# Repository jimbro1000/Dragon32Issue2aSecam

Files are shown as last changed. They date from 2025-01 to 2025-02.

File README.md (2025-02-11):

# Dragon 32 Issue 2a (SECAM) Reproduction

This repository contains the KiCad project files
to reproduce the SECAM variation of the Dragon 32
Issue 2a main board.

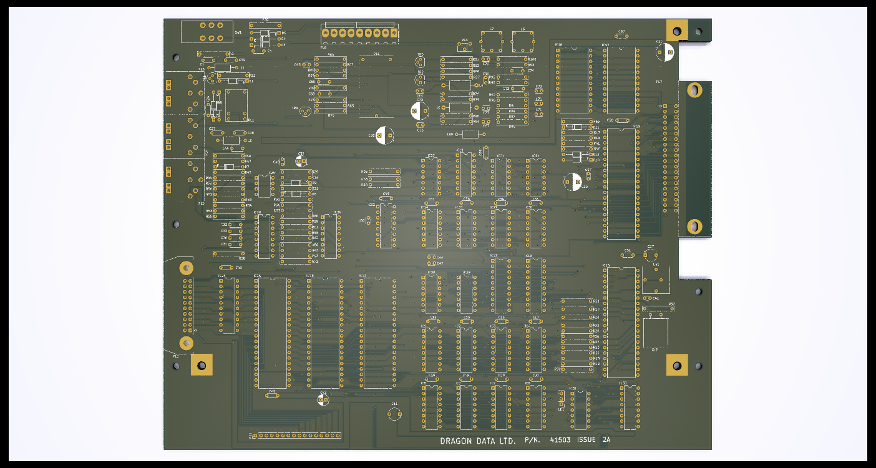
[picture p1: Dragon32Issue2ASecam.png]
Render of PCB top


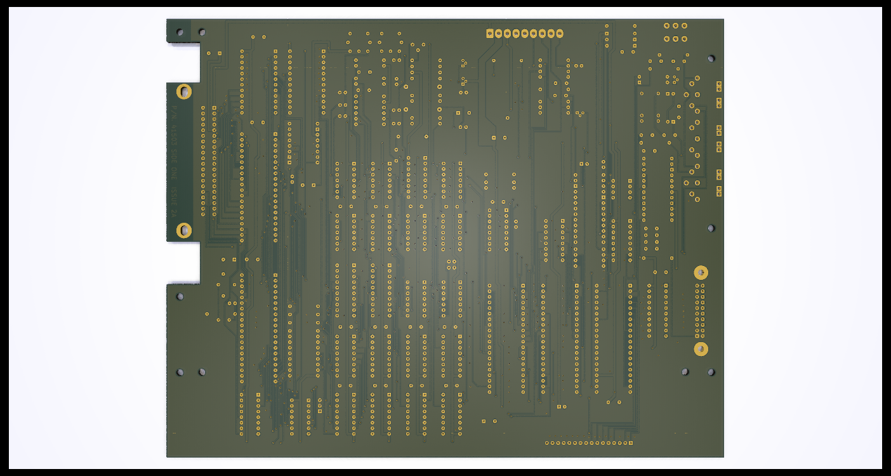
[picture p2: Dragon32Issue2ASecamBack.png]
Render of PCB back


This design requires the SECAM power board to operate
correctly and will not work with the standard board.
See https://github.com/jimbro1000/Dragon32PowerSecam

## Notes

The board incorporates some factory bodges to simplify
assembly efforts.

A front and back ground plane fill has also been added
along with effort to make sure that a ground plane is 
present across most of the board.

## Video Circuit Changes

Compared to the original Dragon 32 (in PAL or NTSC form)
the SECAM version of the design requires a significant 
level of additional work to generate a viable composite
signal.

The most significant change is that the board does not 
make use of a modulator chip (the LM1889N is used on
the PAL version). Instead the generation of the FM based
composite signal is generated through discrete components.

The board is effectively split into two areas. The regular
PAL design (with a few small tweaks) and the SECAM composite
generation - located in the north section of the PCB.

## Power Board Changes

While the same 9 wire interconnect is present on both
designs, the SECAM version repurposes the 5 non-voltage
connections making the power board incompatible with the
PAL/NTSC main board and the SECAM main board incompatible
with the PAL/NTSC power board.

The original pin out provided ground, composite, audio, 5v
and a bias voltage.

The SECAM board uses the same pins as audio, composite,
luma, phiA and phiB (the last 3 forming a YPrPb signal). 
By passing the raw output of the VDG to the power board
there is space to perform additional transformation into
a genuine RGB output that is sorely missing from the original.

### RGB Calculation

The transformation is performed in two stages - first to
homogenise the signal levels of the VDG output (while it 
broadly follows the YPrPb format it doesn't meet the requried
signal voltages). The second stage performs some analogue
computation to create R-Y, G-Y and B-Y components. These
then can be added to the homogenised Y signal to create
the three R, G and B signals.

An exta calculation is needed to isolate the sync signal
that appears on the G channel.

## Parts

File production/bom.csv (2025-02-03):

Designator | Footprint | Quantity | Value | LCSC Part #
C1, C38, C39, C43, C45 | C_Disc_D4.3mm_W1.9mm_P5.00mm | 5 | 0.01uF
C11, C37 | CP_Radial_Tantal_D5.5mm_P5.00mm | 2 | 4.7uF
C14, C15, C16, C17, C18, C19, C20, C21, C27, C4, C50, C51, C52 | C_Disc_D4.3mm_W1.9mm_P5.00mm | 13 | 0.1uF
C22, C23, C36 | CP_Radial_D8.0mm_P5.00mm | 3 | 100uF
C26 | C_Disc_D4.3mm_W1.9mm_P5.00mm | 1 | 2.2nF
C30, C31, C32, C33, C44 | C_Disc_D5.0mm_W2.5mm_P5.00mm | 5 | 22nF
C35, C42 | CP_Radial_D5.0mm_P2.50mm | 2 | 10uF
C40 | C_Radial_Special | 1 | 22pF
C41 | C_Disc_D3.0mm_W1.6mm_P2.50mm | 1 | 33pF
C46, C60 | C_Disc_D3.0mm_W2.0mm_P2.50mm | 2 | 180pF
C47, C61, C65, C67, C70, C71, C72, C75, C76, C77 | C_Disc_D3.0mm_W2.0mm_P2.50mm | 10 | 100pF
C48 | C_Disc_D3.0mm_W2.0mm_P2.50mm | 1 | 22pF
C49, C53, C54, C55, C56 | C_Disc_D4.3mm_W1.9mm_P5.00mm | 5 | 100nF
C68, C69, C73, C74 | C_Disc_D4.7mm_W2.5mm_P5.00mm | 4 | 100nF
C78 | CP_Radial_D8.0mm_P5.00mm | 1 | 10uF
C97, C98 | C_Disc_D3.0mm_W2.0mm_P2.50mm | 2 | 33nF
C99 | C_Disc_D4.7mm_W2.5mm_P5.00mm | 1 | 180pF
D1, D10, D11, D12, D2, D3, D4, D5, D6, D7, D8, D9 | D_DO-35_SOD27_P12.70mm_Horizontal | 12 | 1N914
DL1 | Delay_Line-V9663 | 1 | 390ns 1K1
IC1, IC2, IC3, IC4, IC5, IC6, IC7, IC8 | DIP-16_W7.62mm | 8 | M3732H-20RS
IC11 | DIP-16_W7.62mm | 1 | MC14053
IC12 | DIP-40_W15.24mm | 1 | MC6847
IC13 | DIP-20_W7.62mm | 1 | 74LS273N
IC14 | DIP-14_W7.62mm | 1 | 74LS86AN
IC15 | DIP-40_W15.24mm | 1 | MC6883
IC16, IC24 | DIP-20_W7.62mm | 2 | 74LS244N
IC17, IC18 | DIP-24_W15.24mm | 2 | 68A364
IC19 | DIP-40_W15.24mm | 1 | MC6809E
IC20 | DIP-16_W7.62mm | 1 | MC14529B
IC21 | DIP-14_W7.62mm | 1 | 74LS74
IC22 | DIP-14_W7.62mm | 1 | 74LS00N
IC23 | DIP-14_W7.62mm | 1 | 74ALS74N
IC25 | DIP-8_W7.62mm | 1 | LM393P
IC26, IC35 | DIP-40_W15.24mm | 2 | MC6821
IC27 | DIP-14_W7.62mm | 1 | 74LS20N
IC28, IC29 | DIP-14_W7.62mm | 2 | 74LS393N
IC30 | DIP-14_W7.62mm | 1 | 74LS32N
IC31 | DIP-14_W7.62mm | 1 | 74LS02N
IC32 | DIP-16_W7.62mm | 1 | 74LS390
IC33 | DIP-16_W7.62mm | 1 | 74LS138N
IC34 | DIP-16_W7.62mm | 1 | MC14050BCP
IC44 | DIP-14_W7.62mm | 1 | MC3346
L1, L2, L99 | L_Axial_L7.0mm_D3.3mm_P12.70mm_Horizontal_Fastron_MICC | 3 | 3.3uH
L4 | L_Axial_L9.5mm_D4.0mm_P15.24mm_Horizontal_Fastron_SMCC | 1 | 22uH
L5 | L_Axial_L9.5mm_D4.0mm_P15.24mm_Horizontal_Fastron_SMCC | 1 | 3.3uH
L6, L7 | TOKO_RCL_10K | 2 | 10.7MHz
LK2 | PinHeader_1x03_P2.54mm_Vertical | 1 | LK2
PL1 | PinHeader_1x16_P2.54mm_Vertical | 1 | Dragon Keyboard
PL2 | IDC-Header_2x10-1MP_P2.54mm_Latch_Horizontal | 1 | Printer
PL3 | DIN-6_DELTRON_671-0601_Horizontal | 1 | DIN-6 J/S R
PL4 | DIN-5_DELTRON_671-0501_45deg_Horizontal | 1 | DIN-5 (180) Cassette
PL5 | DIN-6_DELTRON_671-0601_Horizontal | 1 | DIN-6 J/S L
PL6 | Molex_KK-396_A-41791-0009_1x09_P3.96mm_Vertical | 1 | Power Board Interconnect
PL7 | Edge_2x20_P2.54mm_OvalMP | 1 | EDAC 392-040-558-201
R1 | R_Axial_DIN0309_L9.0mm_D2.5mm_P12.70mm_Horizontal | 1 | 100R
R100, R91, R92, R93 | R_Axial_DIN0309_L9.0mm_D2.5mm_P12.70mm_Horizontal | 4 | 6K5
R12, R19, R20, R21, R22, R23, R24, R25, R26, R27, R28 | R_Axial_DIN0309_L9.0mm_D2.5mm_P12.70mm_Horizontal | 11 | 22R
R13, R14, R30, R31, R32, R38, R39, R40, R41, R63, R72 | R_Axial_DIN0309_L9.0mm_D2.5mm_P12.70mm_Horizontal | 11 | 4K7
R16 | R_Axial_DIN0309_L9.0mm_D2.5mm_P12.70mm_Horizontal | 1 | 33K
R29 | R_Axial_DIN0309_L9.0mm_D2.5mm_P12.70mm_Horizontal | 1 | 68K
R33 | R_Axial_DIN0309_L9.0mm_D2.5mm_P12.70mm_Horizontal | 1 | 1K8
R34, R47 | R_Axial_DIN0309_L9.0mm_D2.5mm_P12.70mm_Horizontal | 2 | 8K2
R35 | R_Axial_DIN0309_L9.0mm_D2.5mm_P12.70mm_Horizontal | 1 | 12K
R36, R64 | R_Axial_DIN0309_L9.0mm_D2.5mm_P12.70mm_Horizontal | 2 | 100K
R37 | R_Axial_DIN0309_L9.0mm_D2.5mm_P12.70mm_Horizontal | 1 | 1K5
R42, R43, R55, R56 | R_Axial_DIN0309_L9.0mm_D2.5mm_P12.70mm_Horizontal | 4 | 10K
R45 | R_Axial_DIN0309_L9.0mm_D2.5mm_P12.70mm_Horizontal | 1 | 6K8
R46 | R_Axial_DIN0309_L9.0mm_D2.5mm_P12.70mm_Horizontal | 1 | 220R
R48 | R_Axial_DIN0309_L9.0mm_D2.5mm_P12.70mm_Horizontal | 1 | 15K
R49, R54 | R_Axial_DIN0309_L9.0mm_D2.5mm_P12.70mm_Horizontal | 2 | 1K
R50, R52 | R_Axial_DIN0309_L9.0mm_D2.5mm_P12.70mm_Horizontal | 2 | 56K
R51 | R_Axial_DIN0309_L9.0mm_D2.5mm_P12.70mm_Horizontal | 1 | 1M5
R53 | R_Axial_DIN0309_L9.0mm_D2.5mm_P12.70mm_Horizontal | 1 | 10M
R57 | R_Axial_DIN0309_L9.0mm_D2.5mm_P12.70mm_Horizontal | 1 | 20K 1%
R58 | R_Axial_DIN0309_L9.0mm_D2.5mm_P12.70mm_Horizontal | 1 | 80K6 1%
R59 | R_Axial_DIN0309_L9.0mm_D2.5mm_P12.70mm_Horizontal | 1 | 160K 1%
R60 | R_Axial_DIN0309_L9.0mm_D2.5mm_P12.70mm_Horizontal | 1 | 330K 1%
R61 | R_Axial_DIN0309_L9.0mm_D2.5mm_P12.70mm_Horizontal | 1 | 40K2 1%
R62 | R_Axial_DIN0309_L9.0mm_D2.5mm_P12.70mm_Horizontal | 1 | 10K 1%
R75, R78, R79, R80, R81, R82, R83, R84, R85, R86, R87, R88, R90, R96 | R_Axial_DIN0309_L9.0mm_D2.5mm_P12.70mm_Horizontal | 14 | 47K
R76, R77, R89 | R_Axial_DIN0309_L9.0mm_D2.5mm_P12.70mm_Horizontal | 3 | 1200uH
R94, R99 | R_Axial_DIN0309_L9.0mm_D2.5mm_P12.70mm_Horizontal | 2 | 1K6
R95, R98 | R_Axial_DIN0309_L9.0mm_D2.5mm_P12.70mm_Horizontal | 2 | 470uH
R97 | R_Axial_DIN0309_L9.0mm_D2.5mm_P12.70mm_Horizontal | 1 | 270R
RL1 | OMRON_G2E | 1 | OMRON G2E
SW1 | Button_AlpsAlpine_SPUN190900 | 1 | RESET
TR1 | TO-92 | 1 | BC141
TR2, TR3, TR4 | TO-92 | 3 | BC238B
VR1 | Potentiometer_ACP_CA6-H2,5_Horizontal | 1 | 10K
XL2 | Crystal_HC49-U_Horizontal | 1 | 14.31818MHz

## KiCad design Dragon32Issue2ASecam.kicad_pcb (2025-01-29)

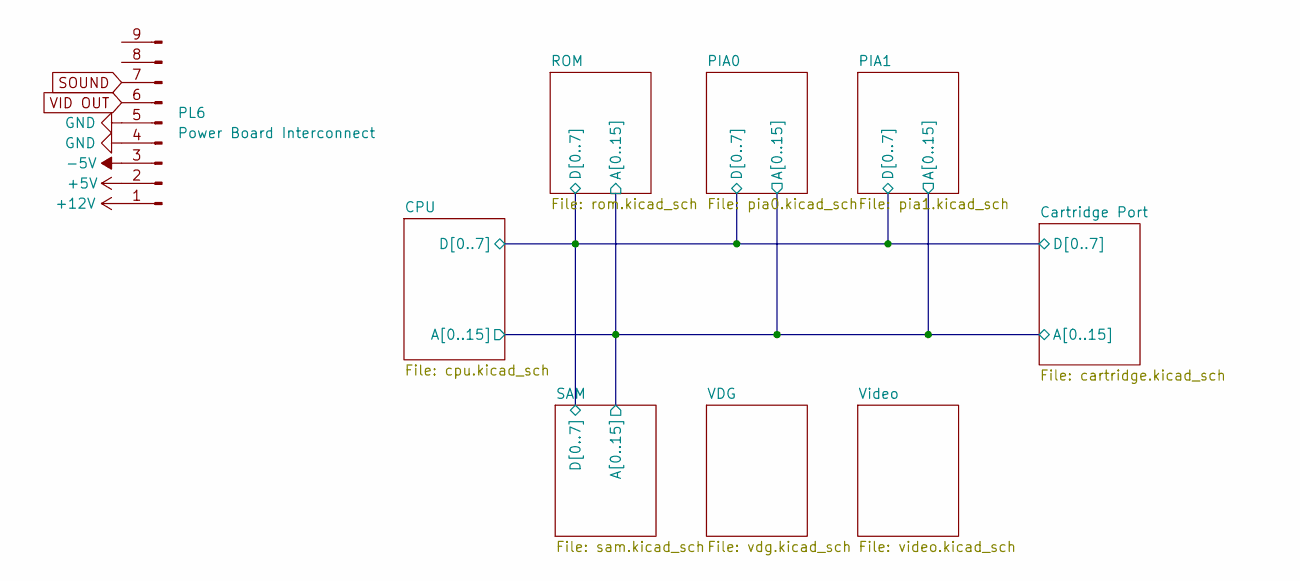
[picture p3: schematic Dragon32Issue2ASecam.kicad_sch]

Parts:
PL6: Power Board Interconnect; Molex_KK-396_A-41791-0009_1x09_P3.96mm_Vertical; DigiKey 2057-LHD-09-TS-ND

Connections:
+5V: PL6.2; also elsewhere on the board
+12V: PL6.1; also elsewhere on the board
-5V: PL6.3
GND: PL6.4, PL6.5; also elsewhere on the board
SOUND: PL6.7; also elsewhere on the board
VID OUT: PL6.6

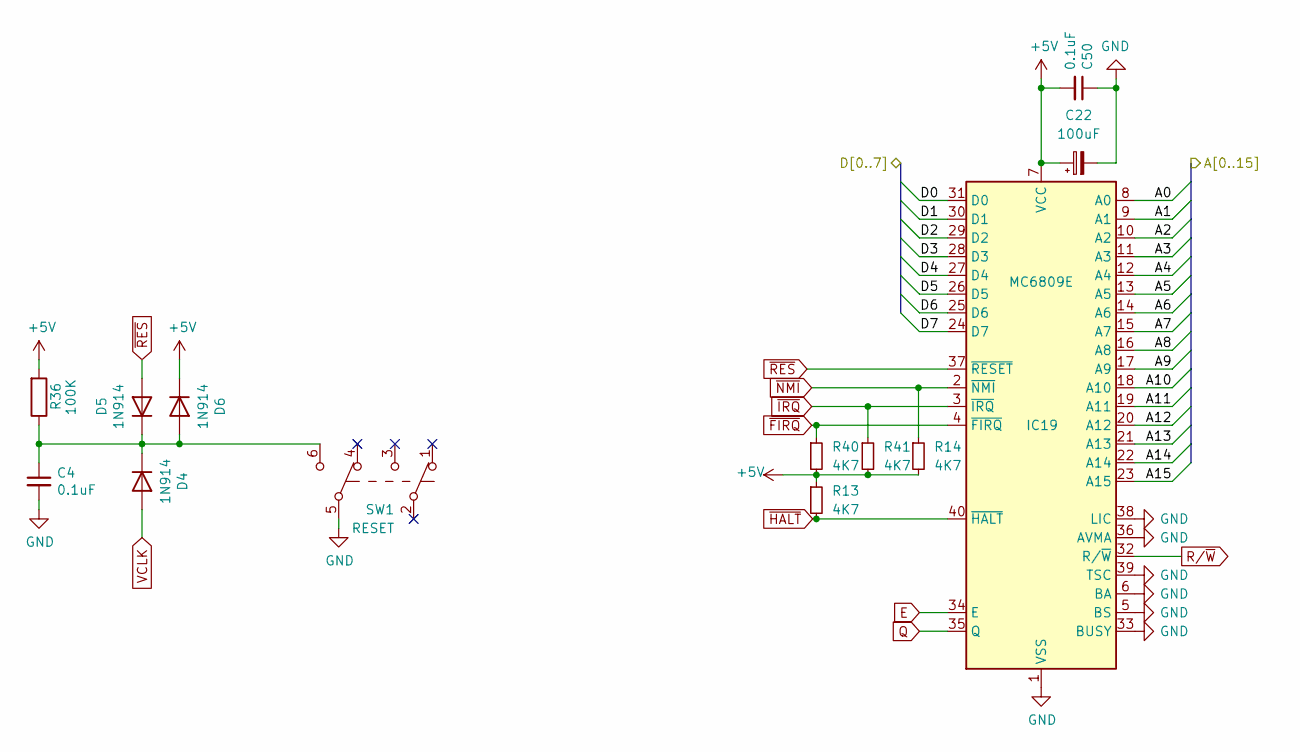
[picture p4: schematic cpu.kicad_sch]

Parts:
C4, C50: 0.1uF; C_Disc_D4.3mm_W1.9mm_P5.00mm; DigiKey BC1101CT-ND
C22: 100uF; CP_Radial_D8.0mm_P5.00mm; DigiKey 732-8598-1-ND
D4, D5, D6: 1N914; D_DO-35_SOD27_P12.70mm_Horizontal; DigiKey 1N914FS-ND
IC19: MC6809E; DIP-40_W15.24mm
R13, R14, R40, R41: 4K7; R_Axial_DIN0309_L9.0mm_D2.5mm_P12.70mm_Horizontal; DigiKey CF14JT4K70CT-ND
R36: 100K; R_Axial_DIN0309_L9.0mm_D2.5mm_P12.70mm_Horizontal; DigiKey CF14JT100KCT-ND
SW1: RESET; Button_AlpsAlpine_SPUN190900; DigiKey 401-1225-ND

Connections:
+5V: C22.1, C50.2, D6.1 (K), IC19.7 (VCC), R13.1, R14.2, R36.2, R40.2, R41.2; also elsewhere on the board
/CPU/A0: IC19.8 (A0); also elsewhere on the board
/CPU/A1: IC19.9 (A1); also elsewhere on the board
/CPU/A2: IC19.10 (A2); also elsewhere on the board
/CPU/A3: IC19.11 (A3); also elsewhere on the board
/CPU/A4: IC19.12 (A4); also elsewhere on the board
/CPU/A5: IC19.13 (A5); also elsewhere on the board
/CPU/A6: IC19.14 (A6); also elsewhere on the board
/CPU/A7: IC19.15 (A7); also elsewhere on the board
/CPU/A8: IC19.16 (A8); also elsewhere on the board
/CPU/A9: IC19.17 (A9); also elsewhere on the board
/CPU/A10: IC19.18 (A10); also elsewhere on the board
/CPU/A11: IC19.19 (A11); also elsewhere on the board
/CPU/A12: IC19.20 (A12); also elsewhere on the board
/CPU/A13: IC19.21 (A13); also elsewhere on the board
/CPU/A14: IC19.22 (A14); also elsewhere on the board
/CPU/A15: IC19.23 (A15); also elsewhere on the board
/CPU/D0: IC19.31 (D0); also elsewhere on the board
/CPU/D1: IC19.30 (D1); also elsewhere on the board
/CPU/D2: IC19.29 (D2); also elsewhere on the board
/CPU/D3: IC19.28 (D3); also elsewhere on the board
/CPU/D4: IC19.27 (D4); also elsewhere on the board
/CPU/D5: IC19.26 (D5); also elsewhere on the board
/CPU/D6: IC19.25 (D6); also elsewhere on the board
/CPU/D7: IC19.24 (D7); also elsewhere on the board
E: IC19.34 (E); also elsewhere on the board
GND: C4.2, C22.2, C50.1, IC19.1 (VSS), IC19.5 (BS), IC19.6 (BA), IC19.33 (BUSY), IC19.36 (AVMA), IC19.38 (LIC), IC19.39 (TSC), SW1.5 (B); also elsewhere on the board
unnamed: C4.1, D4.1 (K), D5.1 (K), D6.2 (A), R36.1, SW1.6 (C)
Q: IC19.35 (Q); also elsewhere on the board
R/~W: IC19.32 (R/~W); also elsewhere on the board
VCLK: D4.2 (A); also elsewhere on the board
~FIRQ: IC19.4 (~FIRQ), R40.1; also elsewhere on the board
~HALT: IC19.40 (~HALT), R13.2; also elsewhere on the board
~IRQ: IC19.3 (~IRQ), R41.1; also elsewhere on the board
~NMI: IC19.2 (~NMI), R14.1; also elsewhere on the board
~RES: D5.2 (A), IC19.37 (~RESET); also elsewhere on the board

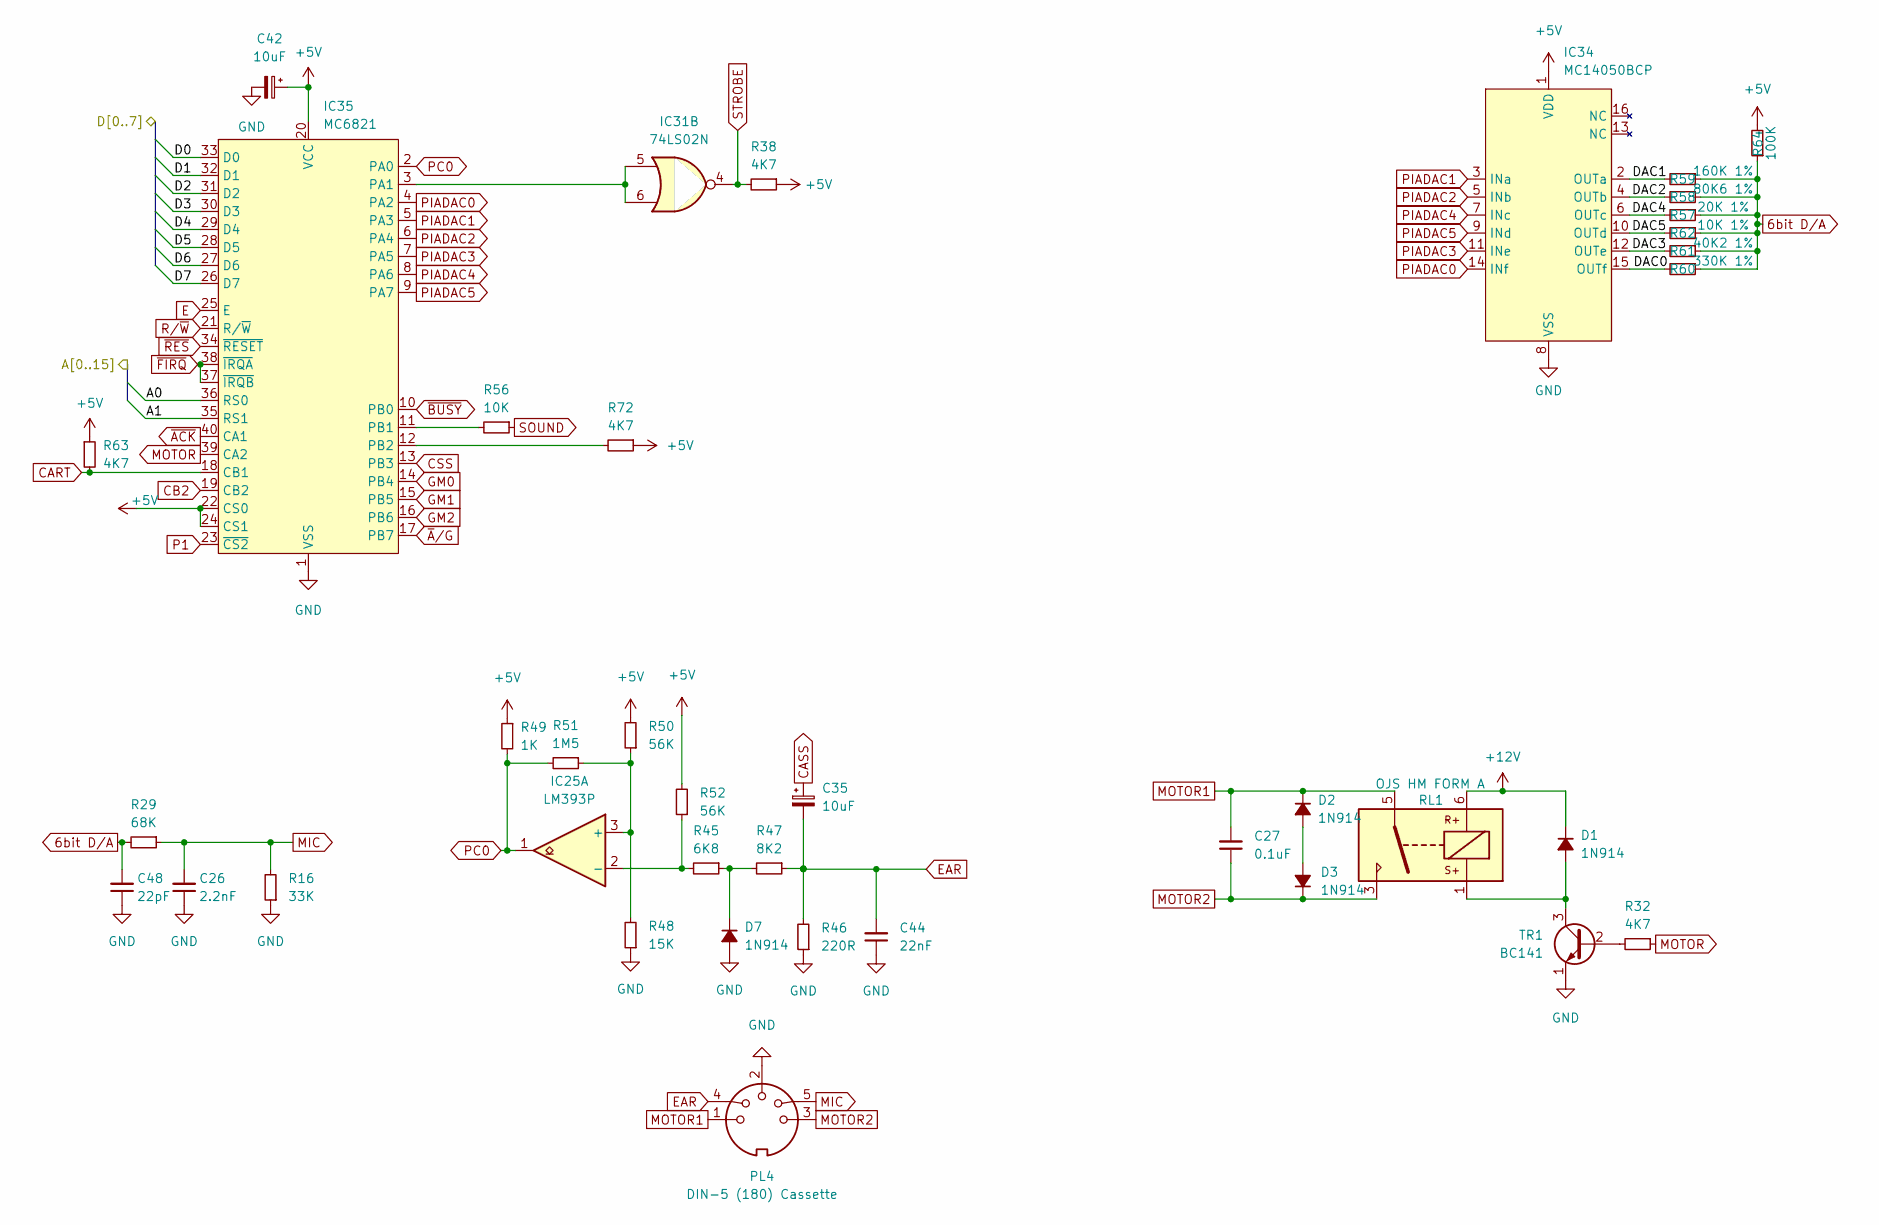
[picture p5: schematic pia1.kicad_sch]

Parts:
C26: 2.2nF; C_Disc_D4.3mm_W1.9mm_P5.00mm; DigiKey BC1074CT-ND
C27: 0.1uF; C_Disc_D4.3mm_W1.9mm_P5.00mm; DigiKey BC1101CT-ND
C35, C42: 10uF; CP_Radial_D5.0mm_P2.50mm; DigiKey 732-8593-1-ND
C44: 22nF; C_Disc_D5.0mm_W2.5mm_P5.00mm; DigiKey BC2677CT-ND
C48: 22pF; C_Disc_D3.0mm_W2.0mm_P2.50mm; DigiKey 399-13930-1-ND
D1, D2, D3, D7: 1N914; D_DO-35_SOD27_P12.70mm_Horizontal; DigiKey 1N914FS-ND
IC25: LM393P; DIP-8_W7.62mm; DigiKey 296-1398-5-ND
IC31: 74LS02N; DIP-14_W7.62mm; DigiKey 296-1627-5-ND
IC34: MC14050BCP; DIP-16_W7.62mm; DigiKey 296-2056-ND
IC35: MC6821; DIP-40_W15.24mm; DigiKey 2156-MC6821CS-2156-ND
PL4: DIN-5 (180) Cassette; DIN-5_DELTRON_671-0501_45deg_Horizontal
R16: 33K; R_Axial_DIN0309_L9.0mm_D2.5mm_P12.70mm_Horizontal; DigiKey CF14JT33K0CT-ND
R29: 68K; R_Axial_DIN0309_L9.0mm_D2.5mm_P12.70mm_Horizontal; DigiKey CF14JT68K0CT-ND
R32, R38, R63: 4K7; R_Axial_DIN0309_L9.0mm_D2.5mm_P12.70mm_Horizontal; DigiKey CF14JT4K70CT-ND
R45: 6K8; R_Axial_DIN0309_L9.0mm_D2.5mm_P12.70mm_Horizontal; DigiKey CF14JT6K80CT-ND
R46: 220R; R_Axial_DIN0309_L9.0mm_D2.5mm_P12.70mm_Horizontal; DigiKey CF14JT220RCT-ND
R47: 8K2; R_Axial_DIN0309_L9.0mm_D2.5mm_P12.70mm_Horizontal; DigiKey CF14JT8K20CT-ND
R48: 15K; R_Axial_DIN0309_L9.0mm_D2.5mm_P12.70mm_Horizontal; DigiKey CF14JT15K0CT-ND
R49: 1K; R_Axial_DIN0309_L9.0mm_D2.5mm_P12.70mm_Horizontal; DigiKey CF14JT1K00CT-ND
R50, R52: 56K; R_Axial_DIN0309_L9.0mm_D2.5mm_P12.70mm_Horizontal; DigiKey CF14JT56K0CT-ND
R51: 1M5; R_Axial_DIN0309_L9.0mm_D2.5mm_P12.70mm_Horizontal; DigiKey CF14JT1M50CT-ND
R56: 10K; R_Axial_DIN0309_L9.0mm_D2.5mm_P12.70mm_Horizontal; DigiKey CF14JT10K0CT-ND
R57: 20K 1%; R_Axial_DIN0309_L9.0mm_D2.5mm_P12.70mm_Horizontal; DigiKey RNF14FTD20K0CT-ND
R58: 80K6 1%; R_Axial_DIN0309_L9.0mm_D2.5mm_P12.70mm_Horizontal; DigiKey RNF14FTD80K6CT-ND
R59: 160K 1%; R_Axial_DIN0309_L9.0mm_D2.5mm_P12.70mm_Horizontal; DigiKey S160CACT-ND
R60: 330K 1%; R_Axial_DIN0309_L9.0mm_D2.5mm_P12.70mm_Horizontal; DigiKey S330KCACT-ND
R61: 40K2 1%; R_Axial_DIN0309_L9.0mm_D2.5mm_P12.70mm_Horizontal; DigiKey RNF14FTD41K2CT-ND
R62: 10K 1%; R_Axial_DIN0309_L9.0mm_D2.5mm_P12.70mm_Horizontal; DigiKey RNF14FTD10K0CT-ND
R64: 100K; R_Axial_DIN0309_L9.0mm_D2.5mm_P12.70mm_Horizontal; DigiKey CF14JT100KCT-ND
R72: 4K7; R_Axial_DIN0309_L9.0mm_D2.5mm_P12.70mm_Horizontal; DigiKey CF14JT10K0CT-ND
RL1: OJS HM FORM A; OJS HM 10A Relay; DigiKey 41-OJS-SH-105HMF,00000-ND
TR1: BC141; TO-92_Inline_Wide; DigiKey SS8050DTACT-ND

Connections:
6bit D/A: C48.2, R29.2, R57.1, R58.1, R59.1, R60.1, R61.1, R62.1, R64.1; also elsewhere on the board
+5V: C42.1, IC34.1 (VDD), IC35.20 (VCC), IC35.22 (CS0), IC35.24 (CS1), R38.1, R49.1, R50.2, R52.2, R63.1, R64.2, R72.1; also elsewhere on the board
+12V: D1.1 (K), RL1.6; also elsewhere on the board
/CPU/A0: IC35.36 (RS0); also elsewhere on the board
/CPU/A1: IC35.35 (RS1); also elsewhere on the board
/CPU/D0: IC35.33 (D0); also elsewhere on the board
/CPU/D1: IC35.32 (D1); also elsewhere on the board
/CPU/D2: IC35.31 (D2); also elsewhere on the board
/CPU/D3: IC35.30 (D3); also elsewhere on the board
/CPU/D4: IC35.29 (D4); also elsewhere on the board
/CPU/D5: IC35.28 (D5); also elsewhere on the board
/CPU/D6: IC35.27 (D6); also elsewhere on the board
/CPU/D7: IC35.26 (D7); also elsewhere on the board
/PIA1/DAC0: IC34.15 (OUTf), R60.2
/PIA1/DAC1: IC34.2 (OUTa), R59.2
/PIA1/DAC2: IC34.4 (OUTb), R58.2
/PIA1/DAC3: IC34.12 (OUTe), R61.2
/PIA1/DAC4: IC34.6 (OUTc), R57.2
/PIA1/DAC5: IC34.10 (OUTd), R62.2
CART: IC35.18 (CB1), R63.2; also elsewhere on the board
CASS: C35.1; also elsewhere on the board
CB2: IC35.19 (CB2); also elsewhere on the board
CSS: IC35.13 (PB3); also elsewhere on the board
E: IC35.25 (E); also elsewhere on the board
EAR: C35.2, C44.2, PL4.4, R46.2, R47.1
GM0: IC35.14 (PB4); also elsewhere on the board
GM1: IC35.15 (PB5); also elsewhere on the board
GM2: IC35.16 (PB6); also elsewhere on the board
GND: C26.1, C42.2, C44.1, C48.1, D7.2 (A), IC34.8 (VSS), IC35.1 (VSS), PL4.2, R16.1, R46.1, R48.1, TR1.1 (E); also elsewhere on the board
MIC: C26.2, PL4.5, R16.2, R29.1
MOTOR: IC35.39 (CA2), R32.1
MOTOR1: C27.2, D2.1 (K), PL4.1, RL1.5
MOTOR2: C27.1, D3.1 (K), PL4.3, RL1.3
unnamed: D1.2 (A), RL1.1, TR1.3 (C)
unnamed: D2.2 (A), D3.2 (A)
unnamed: D7.1 (K), R45.1, R47.2
unnamed: IC25.3 (+), R48.2, R50.1, R51.1
unnamed: IC25.2 (-), R45.2, R52.1
unnamed: IC31.5, IC31.6, IC35.3 (PA1)
unnamed: IC35.11 (PB1), R56.2
unnamed: IC35.12 (PB2), R72.2
unnamed: R32.2, TR1.2 (B)
P1: IC35.23 (~CS2); also elsewhere on the board
PC0: IC25.1, IC35.2 (PA0), R49.2, R51.2
PIADAC0: IC34.14 (INf), IC35.4 (PA2)
PIADAC1: IC34.3 (INa), IC35.5 (PA3)
PIADAC2: IC34.5 (INb), IC35.6 (PA4)
PIADAC3: IC34.11 (INe), IC35.7 (PA5)
PIADAC4: IC34.7 (INc), IC35.8 (PA6)
PIADAC5: IC34.9 (INd), IC35.9 (PA7)
R/~W: IC35.21 (R/~W); also elsewhere on the board
SOUND: R56.1; also elsewhere on the board
STROBE: IC31.4, R38.2; also elsewhere on the board
~ACK: IC35.40 (CA1); also elsewhere on the board
~A/G: IC35.17 (PB7); also elsewhere on the board
~BUSY: IC35.10 (PB0); also elsewhere on the board
~FIRQ: IC35.37 (~IRQB), IC35.38 (~IRQA); also elsewhere on the board
~RES: IC35.34 (~RESET); also elsewhere on the board

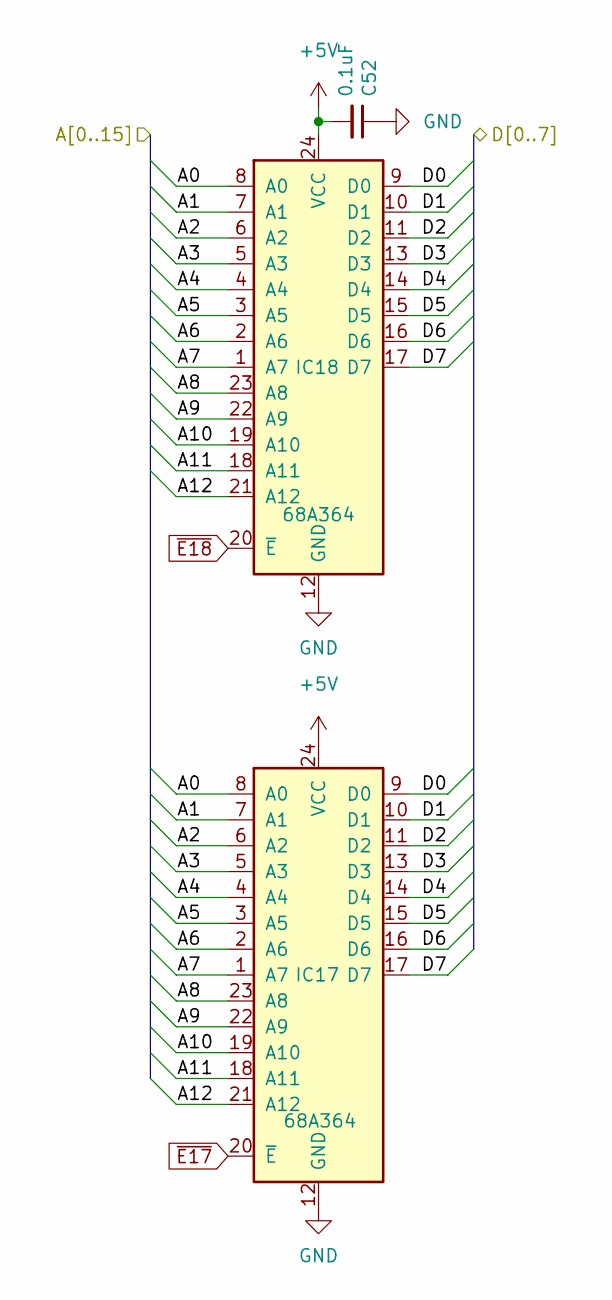
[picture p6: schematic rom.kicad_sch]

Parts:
C52: 0.1uF; C_Disc_D4.3mm_W1.9mm_P5.00mm; DigiKey BC1101CT-ND
IC17, IC18: 68A364; DIP-24_W15.24mm

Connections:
+5V: C52.2, IC17.24 (VCC), IC18.24 (VCC); also elsewhere on the board
/CPU/A0: IC17.8 (A0), IC18.8 (A0); also elsewhere on the board
/CPU/A1: IC17.7 (A1), IC18.7 (A1); also elsewhere on the board
/CPU/A2: IC17.6 (A2), IC18.6 (A2); also elsewhere on the board
/CPU/A3: IC17.5 (A3), IC18.5 (A3); also elsewhere on the board
/CPU/A4: IC17.4 (A4), IC18.4 (A4); also elsewhere on the board
/CPU/A5: IC17.3 (A5), IC18.3 (A5); also elsewhere on the board
/CPU/A6: IC17.2 (A6), IC18.2 (A6); also elsewhere on the board
/CPU/A7: IC17.1 (A7), IC18.1 (A7); also elsewhere on the board
/CPU/A8: IC17.23 (A8), IC18.23 (A8); also elsewhere on the board
/CPU/A9: IC17.22 (A9), IC18.22 (A9); also elsewhere on the board
/CPU/A10: IC17.19 (A10), IC18.19 (A10); also elsewhere on the board
/CPU/A11: IC17.18 (A11), IC18.18 (A11); also elsewhere on the board
/CPU/A12: IC17.21 (A12), IC18.21 (A12); also elsewhere on the board
/CPU/D0: IC17.9 (D0), IC18.9 (D0); also elsewhere on the board
/CPU/D1: IC17.10 (D1), IC18.10 (D1); also elsewhere on the board
/CPU/D2: IC17.11 (D2), IC18.11 (D2); also elsewhere on the board
/CPU/D3: IC17.13 (D3), IC18.13 (D3); also elsewhere on the board
/CPU/D4: IC17.14 (D4), IC18.14 (D4); also elsewhere on the board
/CPU/D5: IC17.15 (D5), IC18.15 (D5); also elsewhere on the board
/CPU/D6: IC17.16 (D6), IC18.16 (D6); also elsewhere on the board
/CPU/D7: IC17.17 (D7), IC18.17 (D7); also elsewhere on the board
GND: C52.1, IC17.12 (GND), IC18.12 (GND); also elsewhere on the board
~E17: IC17.20 (~E); also elsewhere on the board
~E18: IC18.20 (~E); also elsewhere on the board

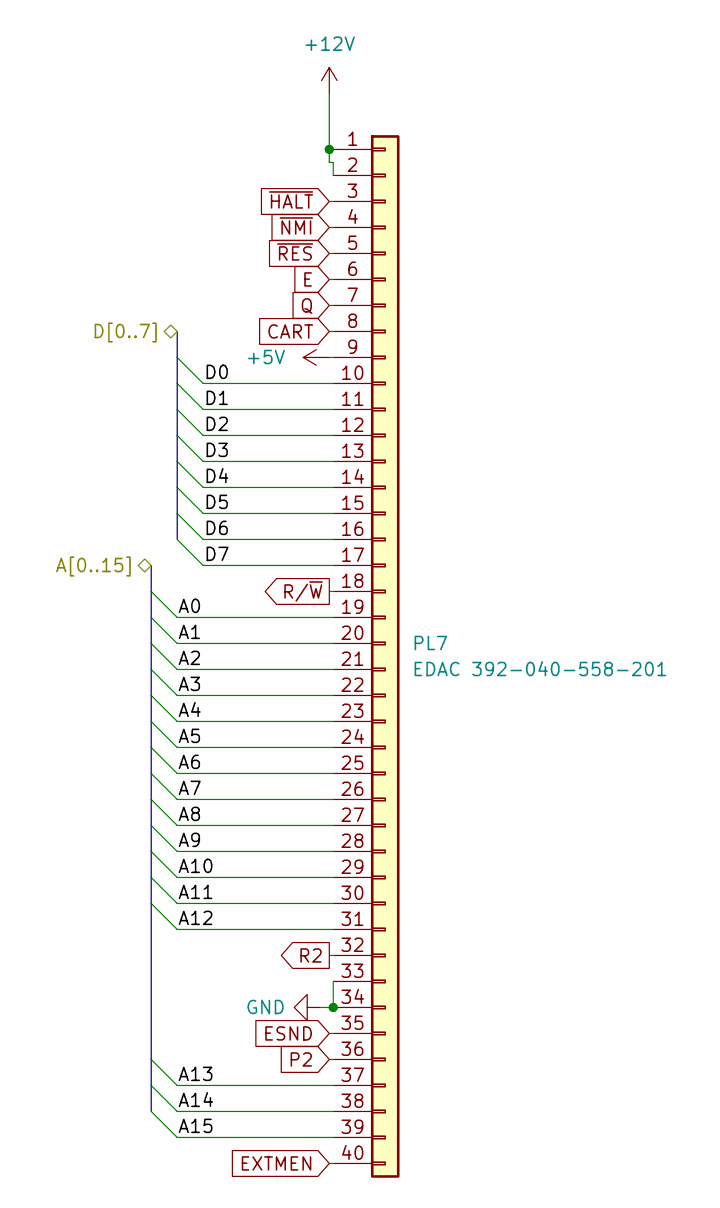
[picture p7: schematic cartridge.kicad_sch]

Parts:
PL7: EDAC 392-040-558-201; Edge_2x20_P2.54mm_OvalMP; DigiKey 151-395-040-558-201-ND

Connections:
+5V: PL7.9; also elsewhere on the board
+12V: PL7.1, PL7.2; also elsewhere on the board
/CPU/A0: PL7.19; also elsewhere on the board
/CPU/A1: PL7.20; also elsewhere on the board
/CPU/A2: PL7.21; also elsewhere on the board
/CPU/A3: PL7.22; also elsewhere on the board
/CPU/A4: PL7.23; also elsewhere on the board
/CPU/A5: PL7.24; also elsewhere on the board
/CPU/A6: PL7.25; also elsewhere on the board
/CPU/A7: PL7.26; also elsewhere on the board
/CPU/A8: PL7.27; also elsewhere on the board
/CPU/A9: PL7.28; also elsewhere on the board
/CPU/A10: PL7.29; also elsewhere on the board
/CPU/A11: PL7.30; also elsewhere on the board
/CPU/A12: PL7.31; also elsewhere on the board
/CPU/A13: PL7.37; also elsewhere on the board
/CPU/A14: PL7.38; also elsewhere on the board
/CPU/A15: PL7.39; also elsewhere on the board
/CPU/D0: PL7.10; also elsewhere on the board
/CPU/D1: PL7.11; also elsewhere on the board
/CPU/D2: PL7.12; also elsewhere on the board
/CPU/D3: PL7.13; also elsewhere on the board
/CPU/D4: PL7.14; also elsewhere on the board
/CPU/D5: PL7.15; also elsewhere on the board
/CPU/D6: PL7.16; also elsewhere on the board
/CPU/D7: PL7.17; also elsewhere on the board
CART: PL7.8; also elsewhere on the board
E: PL7.6; also elsewhere on the board
ESND: PL7.35; also elsewhere on the board
EXTMEN: PL7.40; also elsewhere on the board
GND: PL7.33, PL7.34; also elsewhere on the board
P2: PL7.36; also elsewhere on the board
Q: PL7.7; also elsewhere on the board
R2: PL7.32; also elsewhere on the board
R/~W: PL7.18; also elsewhere on the board
~HALT: PL7.3; also elsewhere on the board
~NMI: PL7.4; also elsewhere on the board
~RES: PL7.5; also elsewhere on the board

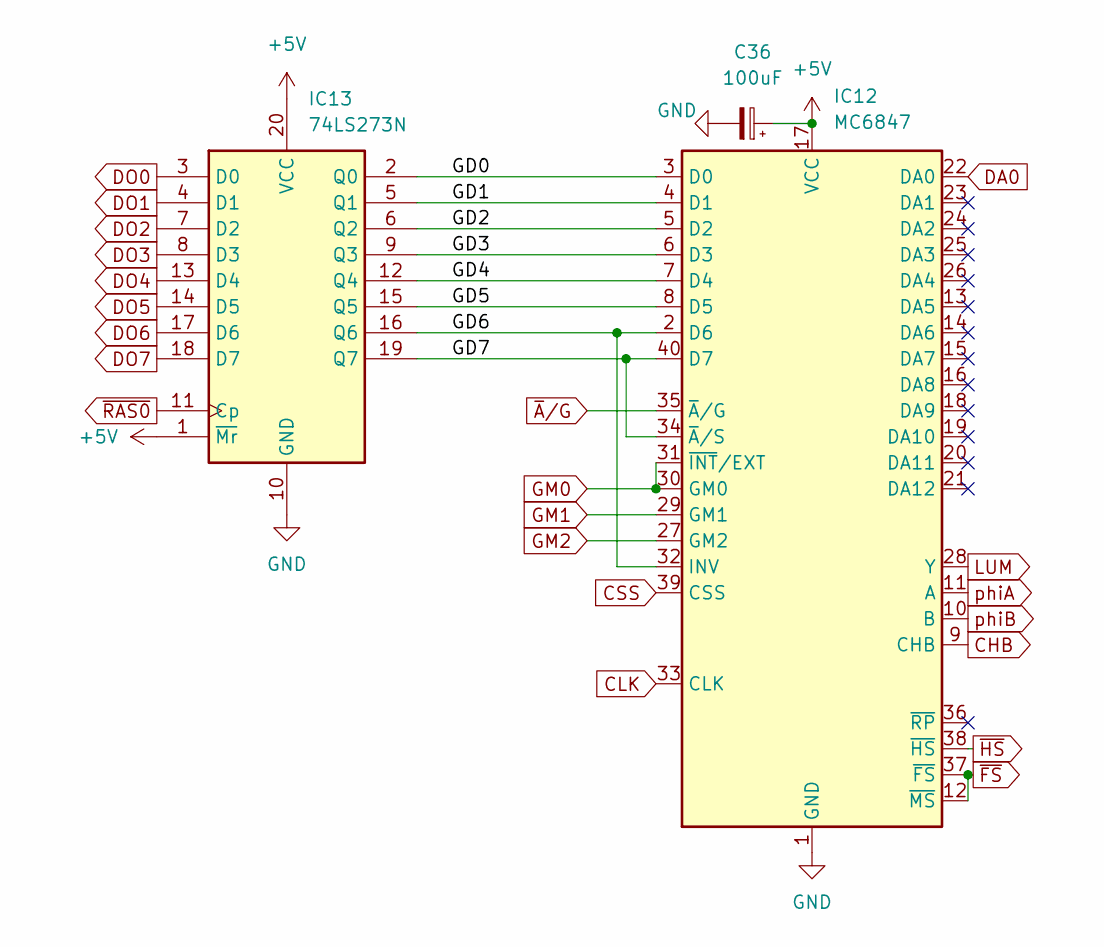
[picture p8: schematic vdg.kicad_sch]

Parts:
C36: 100uF; CP_Radial_D6.3mm_P2.50mm; DigiKey 732-8598-1-ND
IC12: MC6847; DIP-40_W15.24mm
IC13: 74LS273N; DIP-20_W7.62mm; DigiKey 296-1657-5-ND

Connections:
+5V: C36.1, IC12.17 (VCC), IC13.1 (~Mr), IC13.20 (VCC); also elsewhere on the board
/VDG/GD0: IC12.3 (D0), IC13.2 (Q0)
/VDG/GD1: IC12.4 (D1), IC13.5 (Q1)
/VDG/GD2: IC12.5 (D2), IC13.6 (Q2)
/VDG/GD3: IC12.6 (D3), IC13.9 (Q3)
/VDG/GD4: IC12.7 (D4), IC13.12 (Q4)
/VDG/GD5: IC12.8 (D5), IC13.15 (Q5)
/VDG/GD6: IC12.2 (D6), IC12.32 (INV), IC13.16 (Q6)
/VDG/GD7: IC12.34 (~A/S), IC12.40 (D7), IC13.19 (Q7)
CHB: IC12.9 (CHB)
CLK: IC12.33 (CLK)
CSS: IC12.39 (CSS); also elsewhere on the board
DA0: IC12.22 (DA0); also elsewhere on the board
DO0: IC13.3 (D0); also elsewhere on the board
DO1: IC13.4 (D1); also elsewhere on the board
DO2: IC13.7 (D2); also elsewhere on the board
DO3: IC13.8 (D3); also elsewhere on the board
DO4: IC13.13 (D4); also elsewhere on the board
DO5: IC13.14 (D5); also elsewhere on the board
DO6: IC13.17 (D6); also elsewhere on the board
DO7: IC13.18 (D7); also elsewhere on the board
GM0: IC12.30 (GM0), IC12.31 (~INT/EXT); also elsewhere on the board
GM1: IC12.29 (GM1); also elsewhere on the board
GM2: IC12.27 (GM2); also elsewhere on the board
GND: C36.2, IC12.1 (GND), IC13.10 (GND); also elsewhere on the board
LUM: IC12.28 (Y)
phiA: IC12.11 (A)
phiB: IC12.10 (B)
~A/G: IC12.35 (~A/G); also elsewhere on the board
~FS: IC12.12 (~MS), IC12.37 (~FS); also elsewhere on the board
~HS: IC12.38 (~HS)
~RAS0: IC13.11 (Cp); also elsewhere on the board

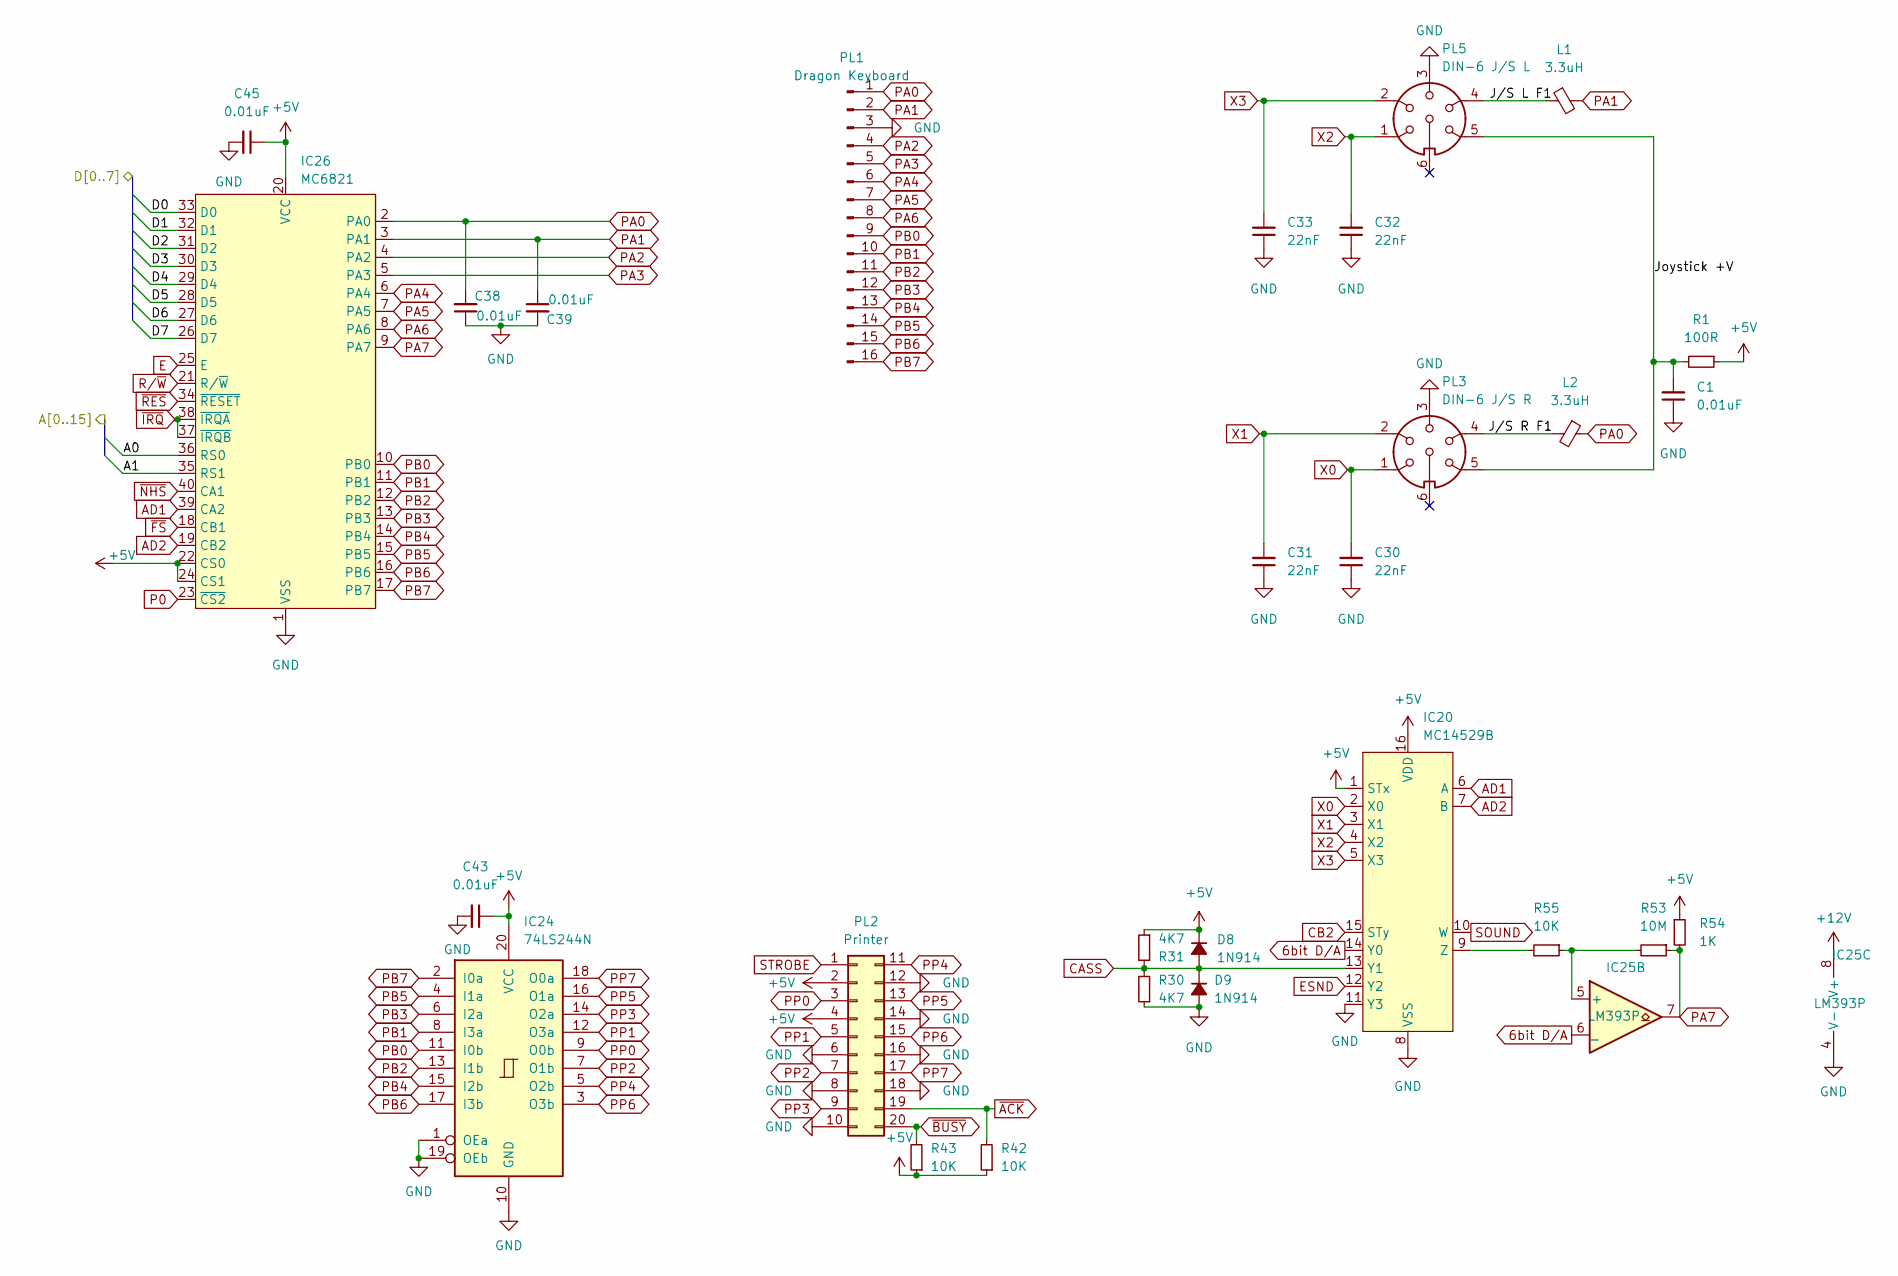
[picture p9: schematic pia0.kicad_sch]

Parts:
C1, C43, C45: 0.01uF; C_Disc_D4.3mm_W1.9mm_P5.00mm; DigiKey BC2662CT-ND
C30, C31, C32, C33: 22nF; C_Disc_D5.0mm_W2.5mm_P5.00mm; DigiKey BC2677CT-ND
C38, C39: 0.01uF; C_Disc_D4.3mm_W1.9mm_P5.00mm; DigiKey BC1101CT-ND
D8, D9: 1N914; D_DO-35_SOD27_P12.70mm_Horizontal; DigiKey 1N914FS-ND
IC20: MC14529B; DIP-16_W7.62mm; DigiKey CD4529BCN-ND
IC24: 74LS244N; DIP-20_W7.62mm; DigiKey 296-1653-5-ND
IC25: LM393P; DIP-8_W7.62mm; DigiKey 296-1398-5-ND
IC26: MC6821; DIP-40_W15.24mm; DigiKey 2156-MC6821CS-2156-ND
L1, L2: 3.3uH; L_Axial_L7.0mm_D3.3mm_P12.70mm_Horizontal_Fastron_MICC; DigiKey 495-5561-1-ND
PL1: Dragon Keyboard; PinHeader_1x16_P2.54mm_Vertical; DigiKey 952-2521-ND
PL2: Printer; IDC-Header_2x10-1MP_P2.54mm_Latch_Horizontal; DigiKey CHR20G-ND
PL3: DIN-6 J/S R; DIN-6_DELTRON_671-0601_Horizontal
PL5: DIN-6 J/S L; DIN-6_DELTRON_671-0601_Horizontal
R1: 100R; R_Axial_DIN0309_L9.0mm_D2.5mm_P12.70mm_Horizontal; DigiKey CF14JT100RCT-ND
R30, R31: 4K7; R_Axial_DIN0309_L9.0mm_D2.5mm_P12.70mm_Horizontal; DigiKey CF14JT4K70CT-ND
R42, R43, R55: 10K; R_Axial_DIN0309_L9.0mm_D2.5mm_P12.70mm_Horizontal; DigiKey CF14JT10K0CT-ND
R53: 10M; R_Axial_DIN0309_L9.0mm_D2.5mm_P12.70mm_Horizontal; DigiKey CF14JT10M0CT-ND
R54: 1K; R_Axial_DIN0309_L9.0mm_D2.5mm_P12.70mm_Horizontal; DigiKey CF14JT1K00CT-ND

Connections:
6bit D/A: IC20.14 (Y0), IC25.6 (_); also elsewhere on the board
+5V: C43.1, C45.1, D8.1 (K), IC20.1 (STx), IC20.16 (VDD), IC24.20 (VCC), IC26.20 (VCC), IC26.22 (CS0), IC26.24 (CS1), PL2.2, PL2.4, R1.1, R31.1, R42.1, R43.1, R54.1; also elsewhere on the board
+12V: IC25.8 (V+); also elsewhere on the board
/CPU/A0: IC26.36 (RS0); also elsewhere on the board
/CPU/A1: IC26.35 (RS1); also elsewhere on the board
/CPU/D0: IC26.33 (D0); also elsewhere on the board
/CPU/D1: IC26.32 (D1); also elsewhere on the board
/CPU/D2: IC26.31 (D2); also elsewhere on the board
/CPU/D3: IC26.30 (D3); also elsewhere on the board
/CPU/D4: IC26.29 (D4); also elsewhere on the board
/CPU/D5: IC26.28 (D5); also elsewhere on the board
/CPU/D6: IC26.27 (D6); also elsewhere on the board
/CPU/D7: IC26.26 (D7); also elsewhere on the board
/PIA0/Joystick +V: C1.2, PL3.5, PL5.5, R1.2
/PIA0/J/S L F1: L1.1, PL5.4
/PIA0/J/S R F1: L2.2, PL3.4
AD1: IC20.6 (A), IC26.39 (CA2)
AD2: IC20.7 (B), IC26.19 (CB2)
CASS: D8.2 (A), D9.1 (K), IC20.13 (Y1), R30.2, R31.2; also elsewhere on the board
CB2: IC20.15 (STy); also elsewhere on the board
E: IC26.25 (E); also elsewhere on the board
ESND: IC20.12 (Y2); also elsewhere on the board
GND: C1.1, C30.1, C31.1, C32.1, C33.1, C38.1, C39.2, C43.2, C45.2, D9.2 (A), IC20.8 (VSS), IC20.11 (Y3), IC24.1 (OEa), IC24.10 (GND), IC24.19 (OEb), IC25.4 (V-), IC26.1 (VSS), PL1.3, PL2.6, PL2.8, PL2.10, PL2.12, PL2.14, PL2.16, PL2.18, PL3.3, PL5.3, R30.1; also elsewhere on the board
unnamed: IC20.9 (Z), R55.2
unnamed: IC25.5 (+), R53.2, R55.1
P0: IC26.23 (~CS2); also elsewhere on the board
PA0: C38.2, IC26.2 (PA0), L2.1, PL1.1
PA1: C39.1, IC26.3 (PA1), L1.2, PL1.2
PA2: IC26.4 (PA2), PL1.4
PA3: IC26.5 (PA3), PL1.5
PA4: IC26.6 (PA4), PL1.6
PA5: IC26.7 (PA5), PL1.7
PA6: IC26.8 (PA6), PL1.8
PA7: IC25.7, IC26.9 (PA7), R53.1, R54.2
PB0: IC24.11 (I0b), IC26.10 (PB0), PL1.9
PB1: IC24.8 (I3a), IC26.11 (PB1), PL1.10
PB2: IC24.13 (I1b), IC26.12 (PB2), PL1.11
PB3: IC24.6 (I2a), IC26.13 (PB3), PL1.12
PB4: IC24.15 (I2b), IC26.14 (PB4), PL1.13
PB5: IC24.4 (I1a), IC26.15 (PB5), PL1.14
PB6: IC24.17 (I3b), IC26.16 (PB6), PL1.15
PB7: IC24.2 (I0a), IC26.17 (PB7), PL1.16
PP0: IC24.9 (O0b), PL2.3
PP1: IC24.12 (O3a), PL2.5
PP2: IC24.7 (O1b), PL2.7
PP3: IC24.14 (O2a), PL2.9
PP4: IC24.5 (O2b), PL2.11
PP5: IC24.16 (O1a), PL2.13
PP6: IC24.3 (O3b), PL2.15
PP7: IC24.18 (O0a), PL2.17
R/~W: IC26.21 (R/~W); also elsewhere on the board
SOUND: IC20.10 (W); also elsewhere on the board
STROBE: PL2.1; also elsewhere on the board
X0: C30.2, IC20.2 (X0), PL3.1
X1: C31.2, IC20.3 (X1), PL3.2
X2: C32.2, IC20.4 (X2), PL5.1
X3: C33.2, IC20.5 (X3), PL5.2
~ACK: PL2.19, R42.2; also elsewhere on the board
~BUSY: PL2.20, R43.2; also elsewhere on the board
~FS: IC26.18 (CB1); also elsewhere on the board
~IRQ: IC26.37 (~IRQB), IC26.38 (~IRQA); also elsewhere on the board
~NHS: IC26.40 (CA1); also elsewhere on the board
~RES: IC26.34 (~RESET); also elsewhere on the board

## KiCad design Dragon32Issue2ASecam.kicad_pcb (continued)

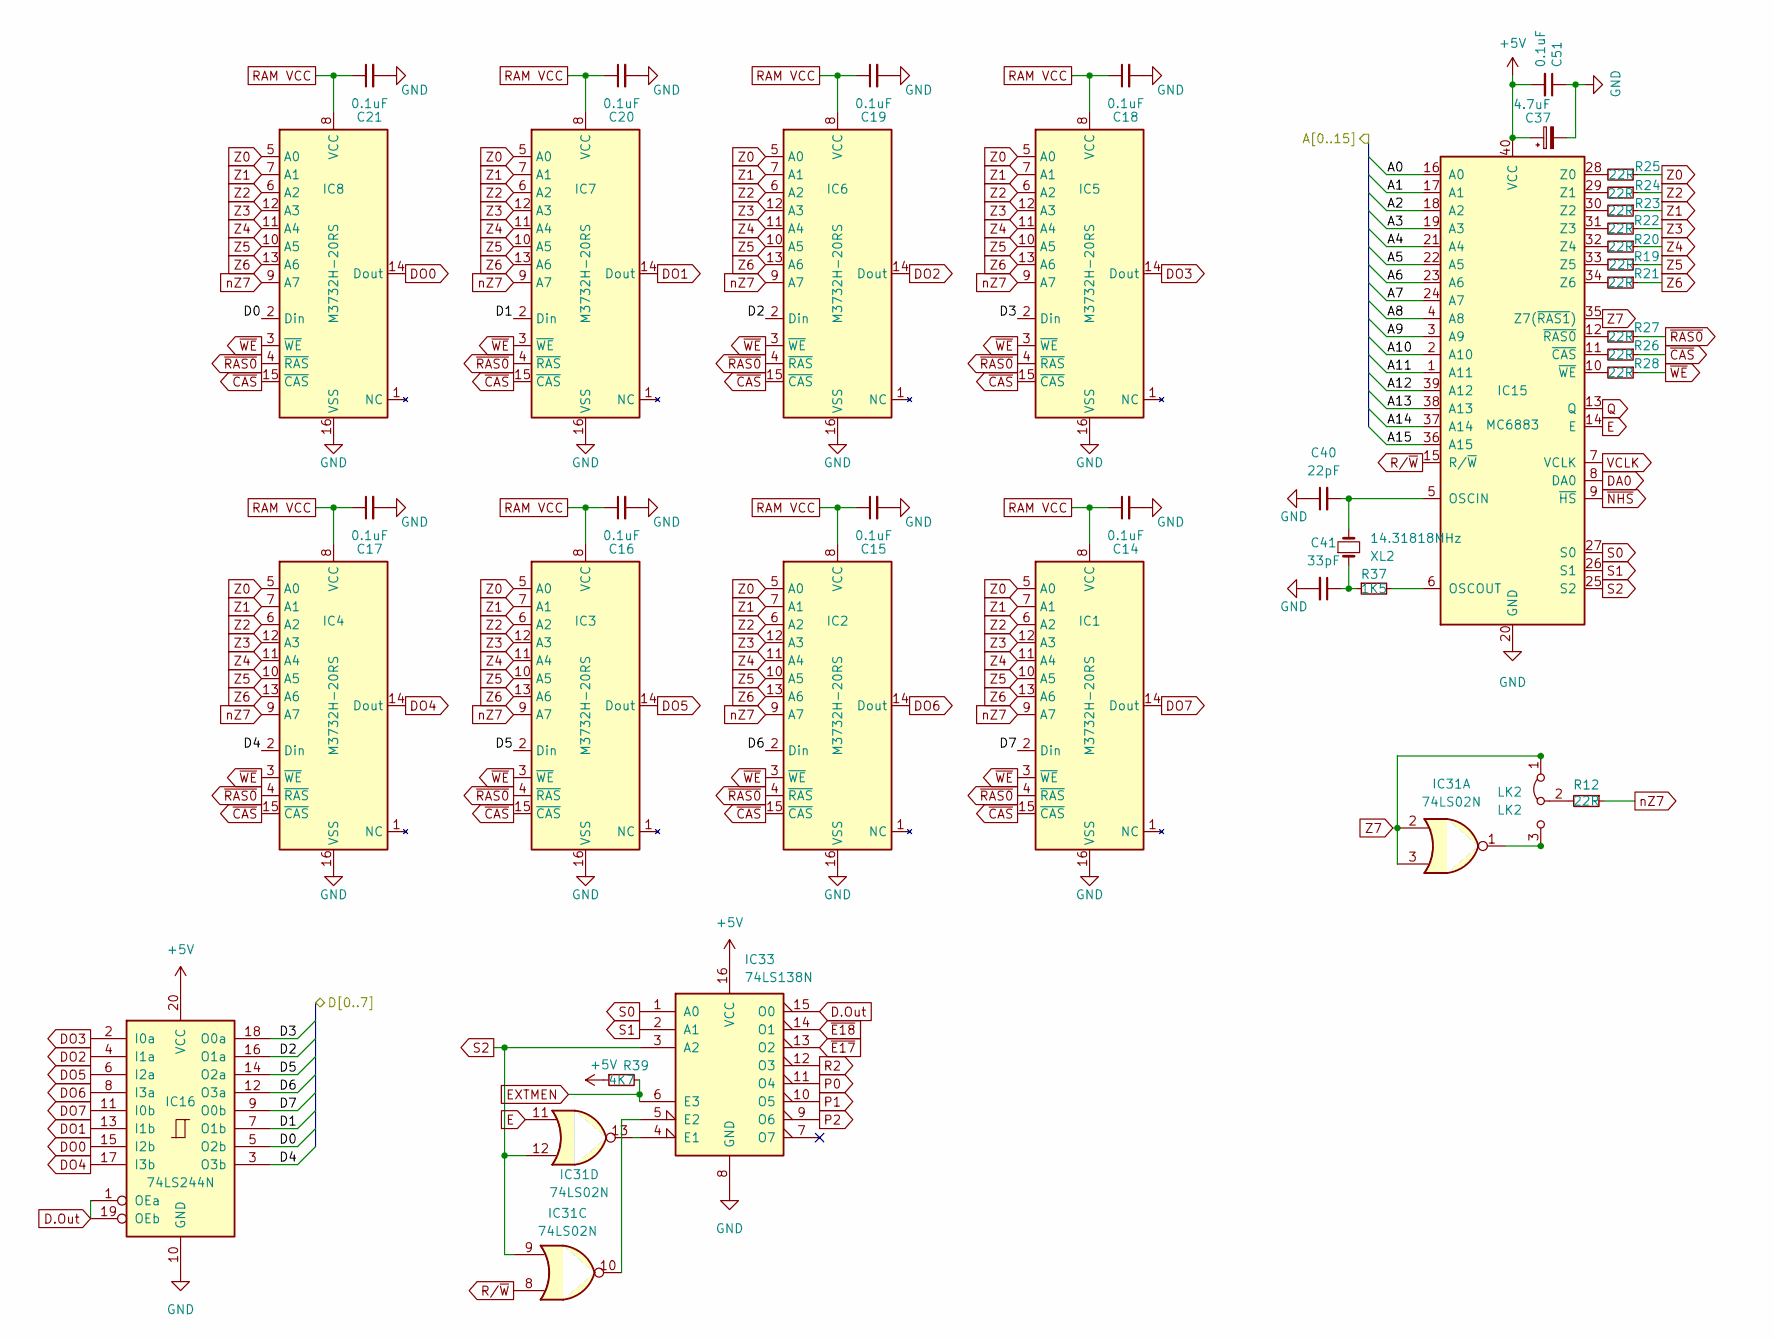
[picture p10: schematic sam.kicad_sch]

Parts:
C14, C15, C16, C17, C18, C19, C20, C21, C51: 0.1uF; C_Disc_D4.3mm_W1.9mm_P5.00mm; DigiKey BC1101CT-ND
C37: 4.7uF; CP_Radial_Tantal_D5.5mm_P5.00mm; DigiKey 478-8984-1-ND
C40: 22pF; C_Radial_Special; DigiKey 399-13930-1-ND
C41: 33pF; C_Disc_D3.0mm_W1.6mm_P2.50mm; DigiKey BC1007CT-ND
IC1, IC2, IC3, IC4, IC5, IC6, IC7, IC8: M3732H-20RS; DIP-16_W7.62mm
IC15: MC6883; DIP-40_W15.24mm
IC16: 74LS244N; DIP-20_W7.62mm; DigiKey 296-1653-5-ND
IC31: 74LS02N; DIP-14_W7.62mm; DigiKey 296-1627-5-ND
IC33: 74LS138N; DIP-16_W7.62mm; DigiKey 296-1639-5-ND
LK2: LK2; PinHeader_1x03_P2.54mm_Vertical; DigiKey 952-2521-ND
R12, R19, R20, R21, R22, R23, R24, R25, R26, R27, R28: 22R; R_Axial_DIN0309_L9.0mm_D2.5mm_P12.70mm_Horizontal; DigiKey CF14JT22R0CT-ND
R37: 1K5; R_Axial_DIN0309_L9.0mm_D2.5mm_P12.70mm_Horizontal; DigiKey CF14JT1K50CT-ND
R39: 4K7; R_Axial_DIN0309_L9.0mm_D2.5mm_P12.70mm_Horizontal; DigiKey CF14JT4K70CT-ND
XL2: 14.31818MHz; Crystal_HC49-U_Horizontal; DigiKey CTX088-ND

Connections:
+5V: C37.1, C51.2, IC15.40 (VCC), IC16.20 (VCC), IC33.16 (VCC), R39.1; also elsewhere on the board
/CPU/A0: IC15.16 (A0); also elsewhere on the board
/CPU/A1: IC15.17 (A1); also elsewhere on the board
/CPU/A2: IC15.18 (A2); also elsewhere on the board
/CPU/A3: IC15.19 (A3); also elsewhere on the board
/CPU/A4: IC15.21 (A4); also elsewhere on the board
/CPU/A5: IC15.22 (A5); also elsewhere on the board
/CPU/A6: IC15.23 (A6); also elsewhere on the board
/CPU/A7: IC15.24 (A7); also elsewhere on the board
/CPU/A8: IC15.4 (A8); also elsewhere on the board
/CPU/A9: IC15.3 (A9); also elsewhere on the board
/CPU/A10: IC15.2 (A10); also elsewhere on the board
/CPU/A11: IC15.1 (A11); also elsewhere on the board
/CPU/A12: IC15.39 (A12); also elsewhere on the board
/CPU/A13: IC15.38 (A13); also elsewhere on the board
/CPU/A14: IC15.37 (A14); also elsewhere on the board
/CPU/A15: IC15.36 (A15); also elsewhere on the board
/CPU/D0: IC8.2 (Din), IC16.5 (O2b); also elsewhere on the board
/CPU/D1: IC7.2 (Din), IC16.7 (O1b); also elsewhere on the board
/CPU/D2: IC6.2 (Din), IC16.16 (O1a); also elsewhere on the board
/CPU/D3: IC5.2 (Din), IC16.18 (O0a); also elsewhere on the board
/CPU/D4: IC4.2 (Din), IC16.3 (O3b); also elsewhere on the board
/CPU/D5: IC3.2 (Din), IC16.14 (O2a); also elsewhere on the board
/CPU/D6: IC2.2 (Din), IC16.12 (O3a); also elsewhere on the board
/CPU/D7: IC1.2 (Din), IC16.9 (O0b); also elsewhere on the board
D.Out: IC16.1 (OEa), IC16.19 (OEb), IC33.15 (O0)
DA0: IC15.8 (DA0); also elsewhere on the board
DO0: IC8.14 (Dout), IC16.15 (I2b); also elsewhere on the board
DO1: IC7.14 (Dout), IC16.13 (I1b); also elsewhere on the board
DO2: IC6.14 (Dout), IC16.4 (I1a); also elsewhere on the board
DO3: IC5.14 (Dout), IC16.2 (I0a); also elsewhere on the board
DO4: IC4.14 (Dout), IC16.17 (I3b); also elsewhere on the board
DO5: IC3.14 (Dout), IC16.6 (I2a); also elsewhere on the board
DO6: IC2.14 (Dout), IC16.8 (I3a); also elsewhere on the board
DO7: IC1.14 (Dout), IC16.11 (I0b); also elsewhere on the board
E: IC15.14 (E), IC31.11; also elsewhere on the board
EXTMEN: IC33.6 (E3), R39.2; also elsewhere on the board
GND: C14.2, C15.2, C16.2, C17.2, C18.2, C19.2, C20.2, C21.2, C37.2, C40.1, C41.2, C51.1, IC1.16 (VSS), IC2.16 (VSS), IC3.16 (VSS), IC4.16 (VSS), IC5.16 (VSS), IC6.16 (VSS), IC7.16 (VSS), IC8.16 (VSS), IC15.20 (GND), IC16.10 (GND), IC33.8 (GND); also elsewhere on the board
unnamed: C41.1, R37.1, XL2.1
unnamed: C40.2, IC15.5 (OSCIN), XL2.2
unnamed: IC15.6 (OSCOUT), R37.2
unnamed: IC15.28 (Z0), R25.2
unnamed: IC15.29 (Z1), R24.2
unnamed: IC15.30 (Z2), R23.2
unnamed: IC15.31 (Z3), R22.2
unnamed: IC15.32 (Z4), R20.2
unnamed: IC15.33 (Z5), R19.2
unnamed: IC15.34 (Z6), R21.2
unnamed: IC15.11 (~CAS), R26.2
unnamed: IC15.12 (~RAS0), R27.2
unnamed: IC15.10 (~WE), R28.2
unnamed: IC31.13, IC33.4 (E1)
unnamed: IC31.10, IC33.5 (E2)
unnamed: IC31.1, LK2.3 (B)
P0: IC33.11 (O4); also elsewhere on the board
P1: IC33.10 (O5); also elsewhere on the board
P2: IC33.9 (O6); also elsewhere on the board
Q: IC15.13 (Q); also elsewhere on the board
R2: IC33.12 (O3); also elsewhere on the board
RAM VCC: C14.1, C15.1, C16.1, C17.1, C18.1, C19.1, C20.1, C21.1, IC1.8 (VCC), IC2.8 (VCC), IC3.8 (VCC), IC4.8 (VCC), IC5.8 (VCC), IC6.8 (VCC), IC7.8 (VCC), IC8.8 (VCC)
R/~W: IC15.15 (R/~W), IC31.8; also elsewhere on the board
S0: IC15.27 (S0), IC33.1 (A0)
S1: IC15.26 (S1), IC33.2 (A1)
S2: IC15.25 (S2), IC31.9, IC31.12, IC33.3 (A2)
VCLK: IC15.7 (VCLK); also elsewhere on the board
Z0: IC1.5 (A0), IC2.5 (A0), IC3.5 (A0), IC4.5 (A0), IC5.5 (A0), IC6.5 (A0), IC7.5 (A0), IC8.5 (A0), R25.1
Z1: IC1.7 (A1), IC2.7 (A1), IC3.7 (A1), IC4.7 (A1), IC5.7 (A1), IC6.7 (A1), IC7.7 (A1), IC8.7 (A1), R23.1
Z2: IC1.6 (A2), IC2.6 (A2), IC3.6 (A2), IC4.6 (A2), IC5.6 (A2), IC6.6 (A2), IC7.6 (A2), IC8.6 (A2), R24.1
Z3: IC1.12 (A3), IC2.12 (A3), IC3.12 (A3), IC4.12 (A3), IC5.12 (A3), IC6.12 (A3), IC7.12 (A3), IC8.12 (A3), R22.1
Z4: IC1.11 (A4), IC2.11 (A4), IC3.11 (A4), IC4.11 (A4), IC5.11 (A4), IC6.11 (A4), IC7.11 (A4), IC8.11 (A4), R20.1
Z5: IC1.10 (A5), IC2.10 (A5), IC3.10 (A5), IC4.10 (A5), IC5.10 (A5), IC6.10 (A5), IC7.10 (A5), IC8.10 (A5), R19.1
Z6: IC1.13 (A6), IC2.13 (A6), IC3.13 (A6), IC4.13 (A6), IC5.13 (A6), IC6.13 (A6), IC7.13 (A6), IC8.13 (A6), R21.1
Z7: IC15.35 (Z7(~RAS1)), IC31.2, IC31.3, LK2.1 (A)
nZ7: IC1.9 (A7), IC2.9 (A7), IC3.9 (A7), IC4.9 (A7), IC5.9 (A7), IC6.9 (A7), IC7.9 (A7), IC8.9 (A7), R12.1
~CAS: IC1.15 (~CAS), IC2.15 (~CAS), IC3.15 (~CAS), IC4.15 (~CAS), IC5.15 (~CAS), IC6.15 (~CAS), IC7.15 (~CAS), IC8.15 (~CAS), R26.1
~E17: IC33.13 (O2); also elsewhere on the board
~E18: IC33.14 (O1); also elsewhere on the board
~NHS: IC15.9 (~HS); also elsewhere on the board
~RAS0: IC1.4 (~RAS), IC2.4 (~RAS), IC3.4 (~RAS), IC4.4 (~RAS), IC5.4 (~RAS), IC6.4 (~RAS), IC7.4 (~RAS), IC8.4 (~RAS), R27.1; also elsewhere on the board
~WE: IC1.3 (~WE), IC2.3 (~WE), IC3.3 (~WE), IC4.3 (~WE), IC5.3 (~WE), IC6.3 (~WE), IC7.3 (~WE), IC8.3 (~WE), R28.1

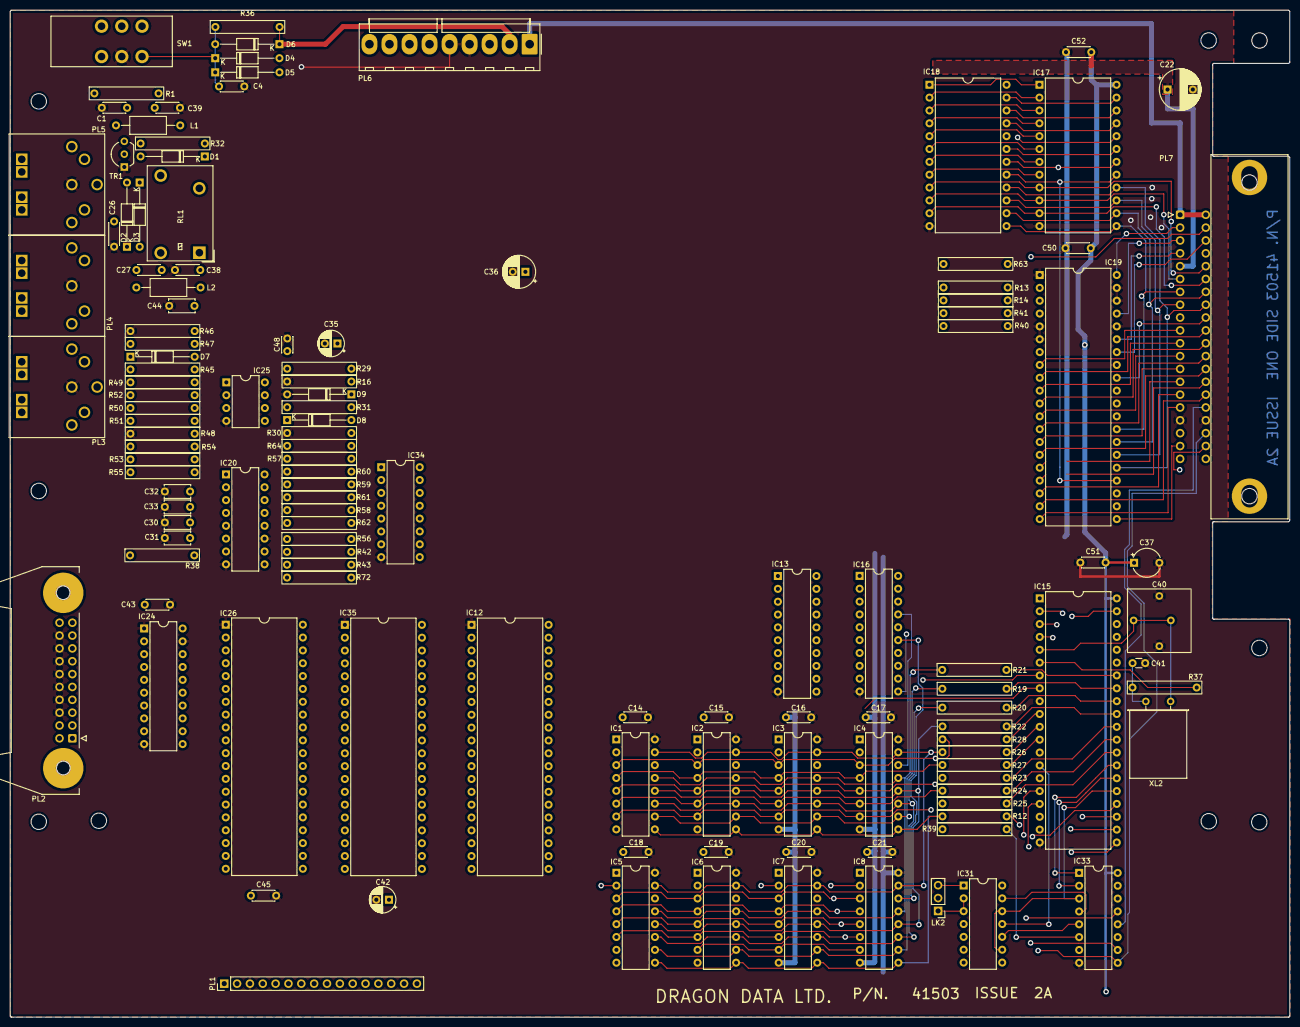
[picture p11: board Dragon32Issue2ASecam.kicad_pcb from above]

Board: 2 copper layers, 253.0 x 199.1 mm, 126 parts (0 on the bottom side), 172 nets.

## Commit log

2025-01-27 add sam and ram
    [Dragon32Issue2ASecam.kicad_pcb, Dragon32Issue2ASecam.kicad_sch, sam.kicad_sch]
2025-01-28 work on memory sub system
    [Dragon32Issue2ASecam.kicad_pcb, cpu.kicad_sch, sam.kicad_sch]
2025-01-29 add PIA and VDG to schematics
    [Dragon32Issue2ASecam.kicad_pcb, Dragon32Issue2ASecam.kicad_sch, cpu.kicad_sch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]
2025-01-29 add video padding circuit
    [pia0.kicad_sch, pia1.kicad_sch, sam.kicad_sch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]
2025-01-31 video circuit tracing
    [Dragon32Issue2ASecam.kicad_sch, cpu.kicad_sch, pia0.kicad_sch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]
2025-02-02 FM generator routing
    [Dragon32Issue2ASecam.kicad_sch, cpu.kicad_sch, pia0.kicad_sch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]
2025-02-03 complete physical layout
    [Dragon32Issue2ASecam.kicad_sch, cpu.kicad_sch, video.kicad_sch]
2025-02-03 fm circuit routing
    [Dragon32Issue2ASecam.kicad_sch, video.kicad_sch]
2025-02-03 trace work complete
    [Dragon32Issue2ASecam.kicad_sch, bom.csv, designators.csv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]
2025-02-05 attach u5 to 4053-pin 15 (B control)
    [video.kicad_sch]
2025-02-11 resolve missing connections
    [Dragon32Issue2ASecam.kicad_sch, sam.kicad_sch, video.kicad_sch]
2025-02-18 add missing power connections
    [video.kicad_sch]
